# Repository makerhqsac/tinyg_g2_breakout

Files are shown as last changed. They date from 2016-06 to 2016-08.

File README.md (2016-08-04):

# TinyG G2 Breakout Board

This board connects on top of an Arduino Due and then a grblshield is connected on top of this shield. This provides a TinyG G2 CNC control board with all the common pins for limit/homing switches and control pendant functionality to be easily connected to the Arduino Due.

OSHBoard Board Rendering

Order from OSHPark [Here](https://oshpark.com/shared_projects/RuvmX1Bc)

[Schematic](https://github.com/makerhqsac/tinyg_g2_breakout/raw/master/tinyg_g2_breakout.pdf)

This is part of an overall TinyG G2 CNC control system. 3D printable files for the enclosure, control pendant and junction box can be
found here:

* Electronics Enclosure: http://www.thingiverse.com/thing:1703914
* Control Pendant: http://www.thingiverse.com/thing:1703922
* Junction Box: http://www.thingiverse.com/thing:1703927

Board in action:

board

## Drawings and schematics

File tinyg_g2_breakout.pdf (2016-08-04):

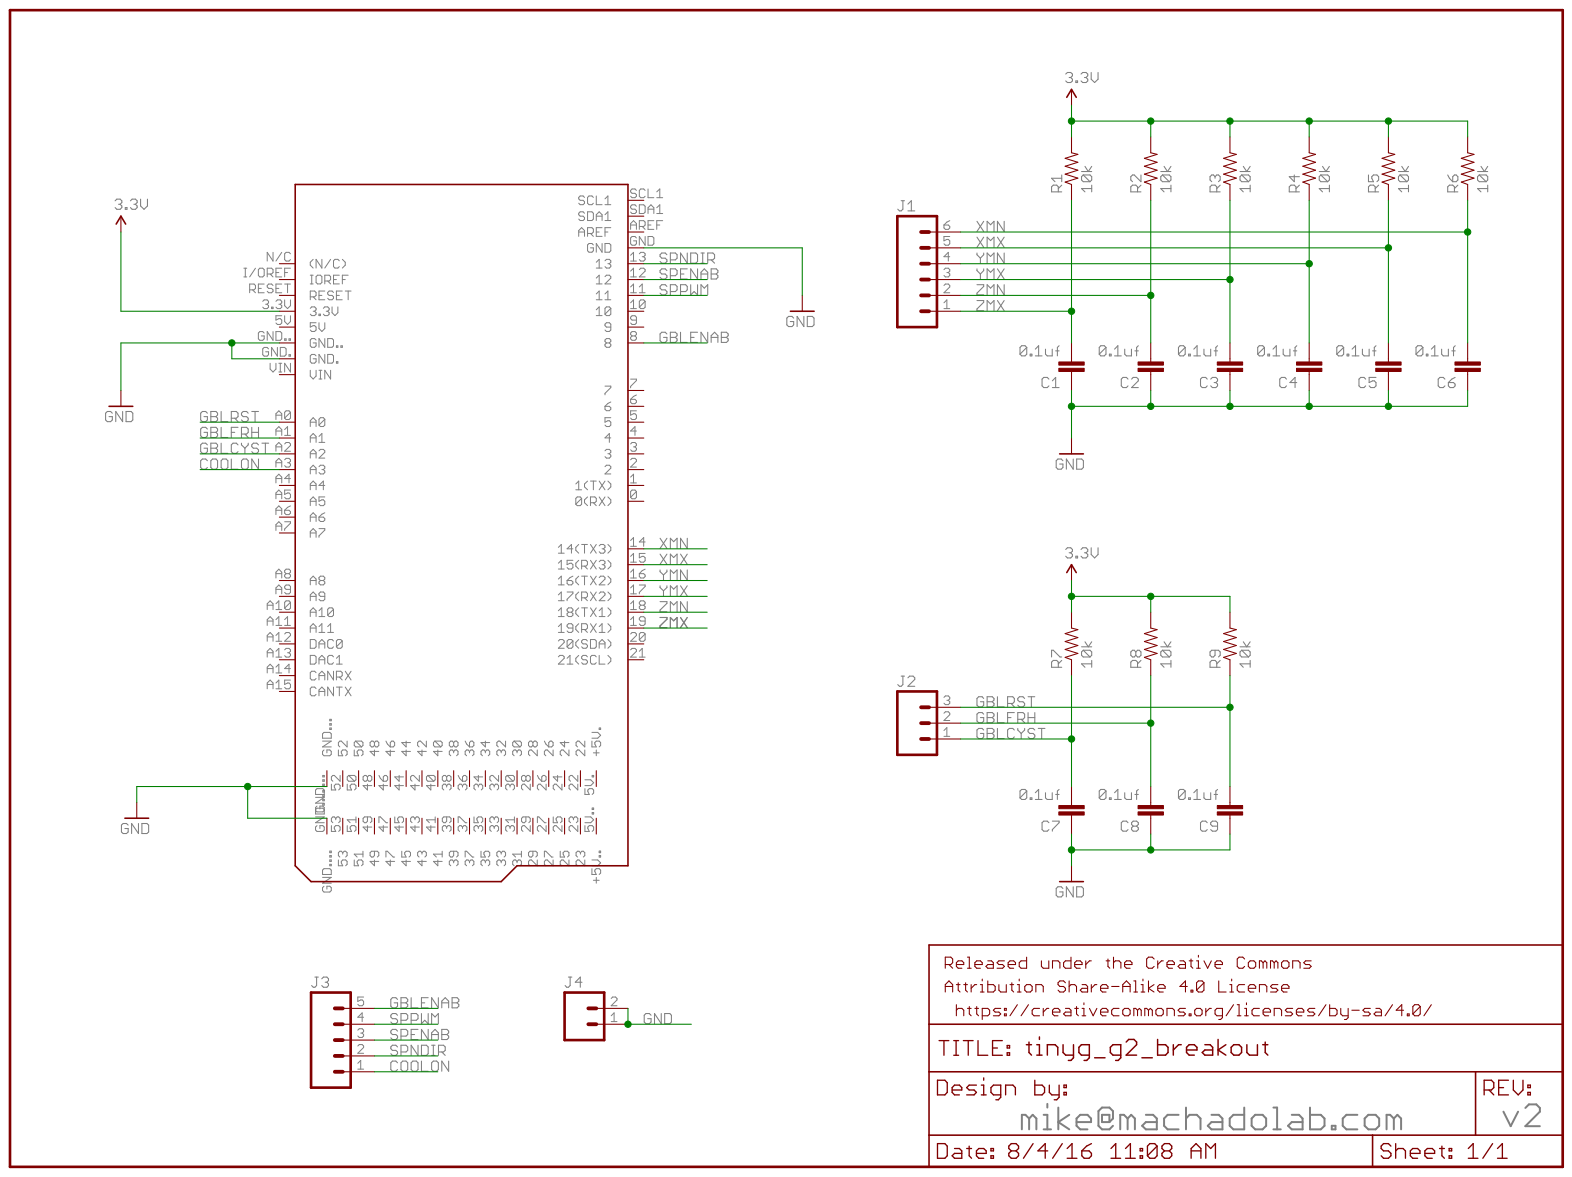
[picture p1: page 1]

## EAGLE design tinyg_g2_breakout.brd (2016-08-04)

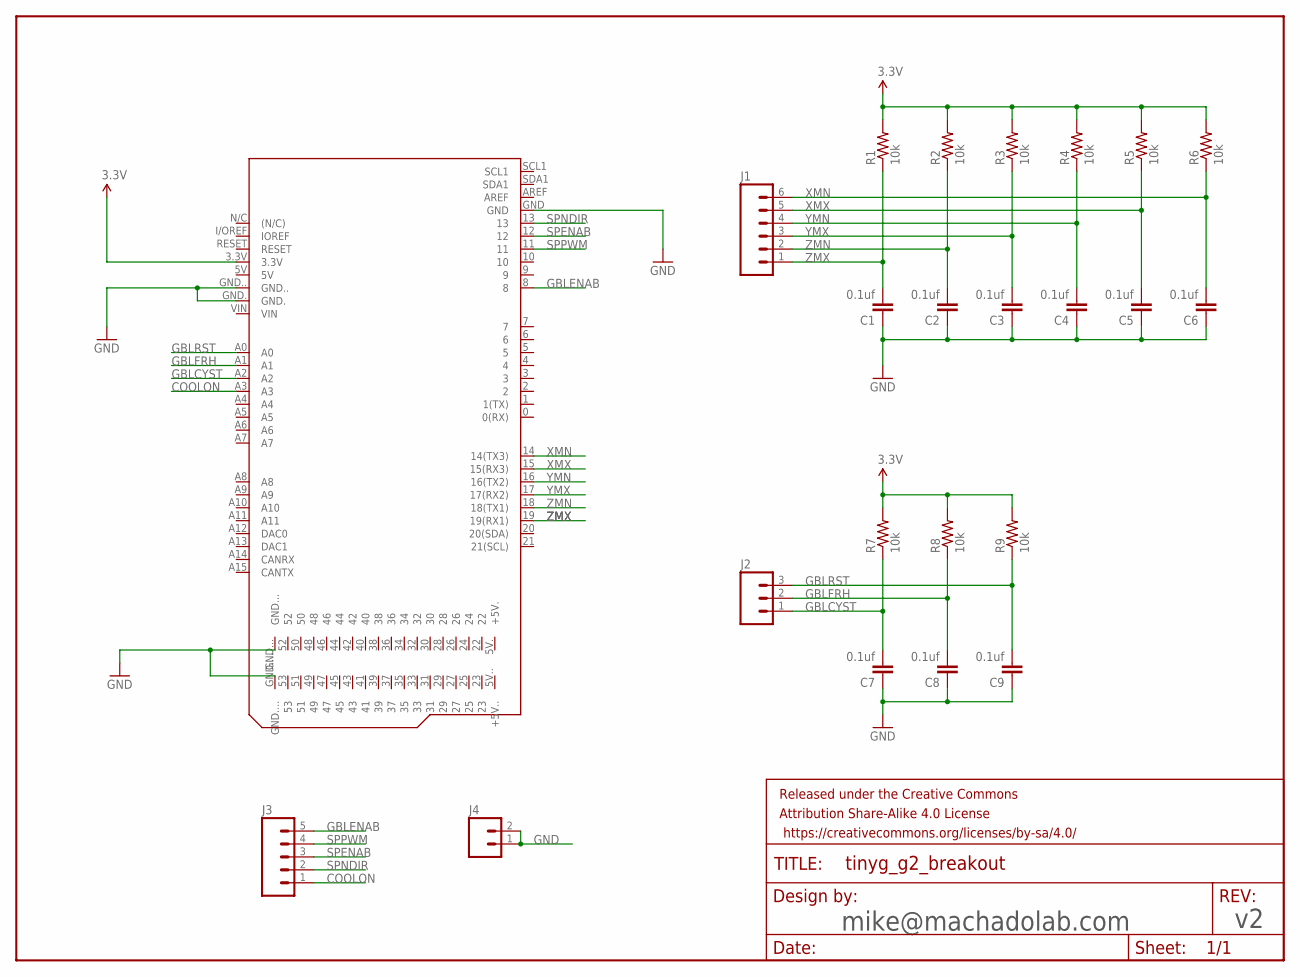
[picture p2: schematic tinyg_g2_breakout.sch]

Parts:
C1, C2, C3, C4, C5, C6, C7, C8, C9: 0.1uf; CAP-PTH-SMALL
FRAME1: v1; CREATIVE_COMMONS
J1: M06SILK_FEMALE_PTH; 1X06
J2: M03PTH; 1X03
J3: M05PTH; 1X05
J4: M02PTH; 1X02
PCB1: ARDUINO_DUE_SHIELD
R1, R2, R3, R4, R5, R6, R7, R8, R9: 10k; AXIAL-0.3

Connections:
3.3V: PCB1.3.3V, R1.P$2 (2), R2.P$2 (2), R3.P$2 (2), R4.P$2 (2), R5.P$2 (2), R6.P$2 (2), R7.P$2 (2), R8.P$2 (2), R9.P$2 (2)
COOLON: J3.1, PCB1.A3
GBLCYST: C7.2, J2.1, PCB1.A2, R7.P$1 (1)
GBLENAB: J3.5, PCB1.8
GBLFRH: C8.2, J2.2, PCB1.A1, R8.P$1 (1)
GBLRST: C9.2, J2.3, PCB1.A0, R9.P$1 (1)
GND: C1.1, C2.1, C3.1, C4.1, C5.1, C6.1, C7.1, C8.1, C9.1, J4.1, J4.2, PCB1.GND, PCB1.GND., PCB1.GND.., PCB1.GND..., PCB1.GND....
SPENAB: J3.3, PCB1.12
SPNDIR: J3.2, PCB1.13
SPPWM: J3.4, PCB1.11
XMN: C6.2, J1.6, PCB1.14 (14(TX3)), R6.P$1 (1)
XMX: C5.2, J1.5, PCB1.15 (15(RX3)), R5.P$1 (1)
YMN: C4.2, J1.4, PCB1.16 (16(TX2)), R4.P$1 (1)
YMX: C3.2, J1.3, PCB1.17 (17(RX2)), R3.P$1 (1)
ZMN: C2.2, J1.2, PCB1.18 (18(TX1)), R2.P$1 (1)
ZMX: C1.2, J1.1, PCB1.19 (19(RX1)), R1.P$1 (1)

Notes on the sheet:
mike@machadolab.com

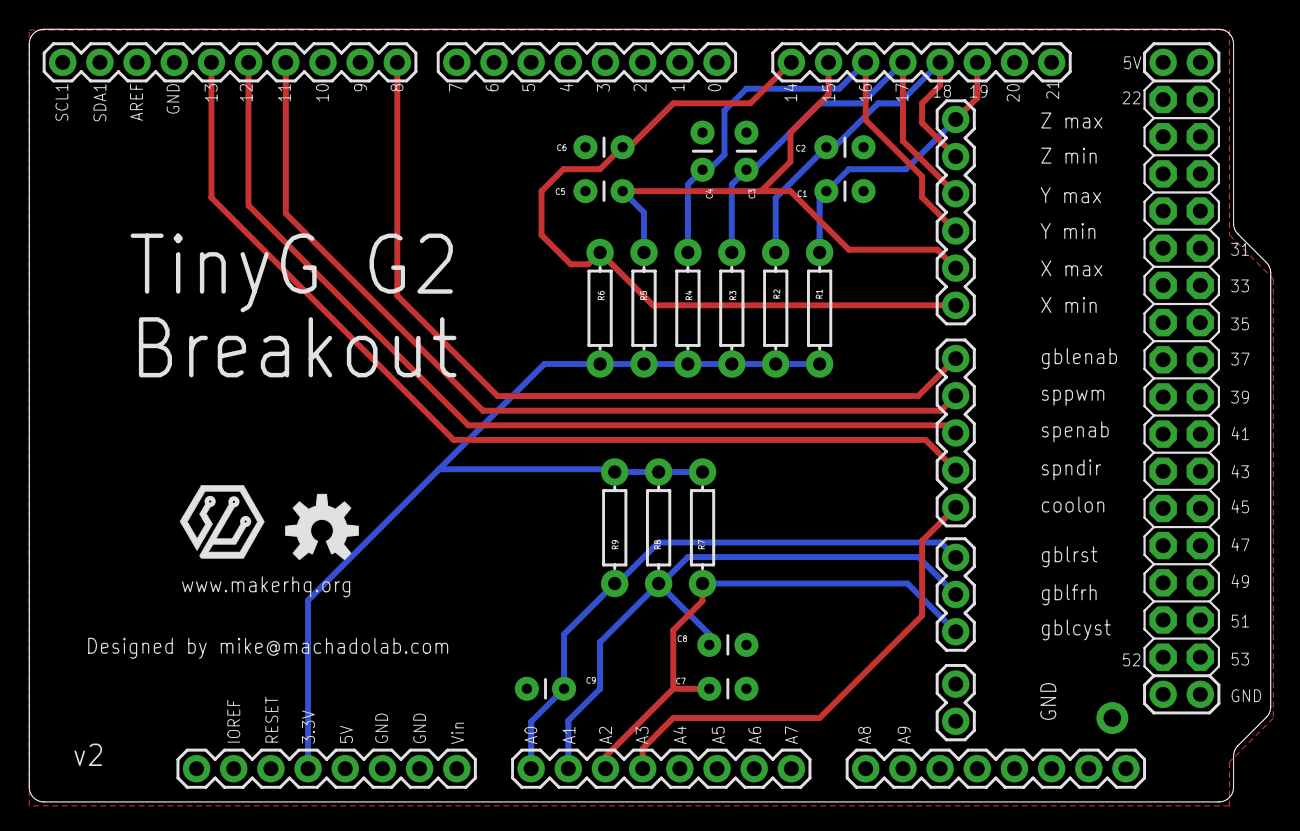
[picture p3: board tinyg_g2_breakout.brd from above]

Board: 2 copper layers, 84.8 x 52.8 mm, 26 parts (0 on the bottom side), 16 nets.

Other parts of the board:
U$1: OSHW-LOGO-M
U$2: MAKERHQ_LOGO_L

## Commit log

2016-06-15 Initial import
    [tinyg_g2_breakout_v1.brd, tinyg_g2_breakout_v1.sch]
2016-06-19 latest changes
    [tinyg_g2_breakout_v1.brd, tinyg_g2_breakout_v1.sch]
2016-08-04 Updated files
    [tinyg_g2_breakout.brd, tinyg_g2_breakout.sch]

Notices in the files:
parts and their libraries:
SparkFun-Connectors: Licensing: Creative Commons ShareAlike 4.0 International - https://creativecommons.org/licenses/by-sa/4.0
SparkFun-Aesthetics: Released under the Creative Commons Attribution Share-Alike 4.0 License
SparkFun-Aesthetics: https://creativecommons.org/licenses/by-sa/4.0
